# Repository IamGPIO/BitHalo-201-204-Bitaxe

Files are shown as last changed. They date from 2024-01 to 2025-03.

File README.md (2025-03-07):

***

### The BitHalo by IAmGPIO of www.thesolomining.co

In the grand tapestry of the cosmos, where stars weave the stories of fate and fortune, the Almighty leaned over to the legendary IAmGpio, whispering through the winds of time, __'Let there be light.'__ With a smirk as wide as the horizon and the casual air of a cosmic pub regular, IAmGpio, the electric alchemist, declared with a mischievous twinkle, 'Hold my beer...' And thus, amidst a backdrop of chuckling constellations, the darkness scurried away, leaving behind a spectacle to be remembered.

During this celestial extravaganza, as the light began to weave and dance through the fabric of space, the Almighty paused, squinted through the cosmic kaleidoscope, and in a moment of divine epiphany, exclaimed in a cockney accent that resonated across the heavens, _'Oi, hold up, this looks a bit like a halo, don’t it?'_ The cosmos held its breath, the stars blinked in amusement, and in that whimsical pause, BitHalo was born. With a hearty chuckle and a nod of approval, the Lord mused, 'Well, ain’t that brilliant? BitHalo it is, then!' And the universe, in all its wonder and wit, echoed with laughter, forever cherishing the birth of BitHalo, a light that forever wears its halo with a determined grin; proving its sidekick, The Bitaxe, is submitting its best efforts to find that elusive block. 
***
-Ok, this didn't happen _**exactly**_ like this....

***

<p align="center">
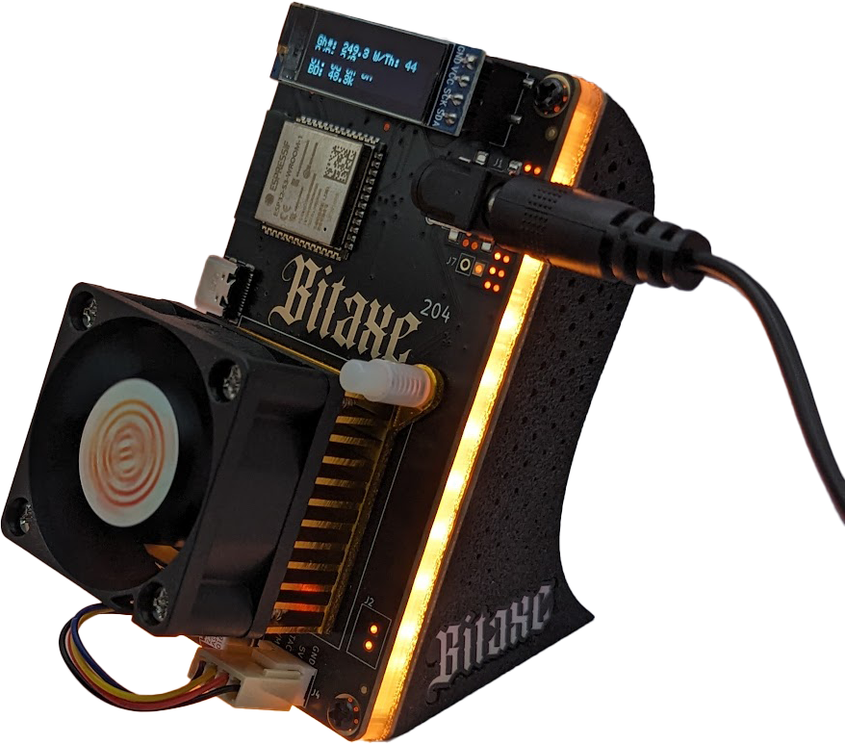
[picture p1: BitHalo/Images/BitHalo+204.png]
Front isometric with logo
  
</p>

***   
License

This project is licensed under the Creative Commons Attribution-ShareAlike 4.0 International License - see the [LICENSE](LICENSE) file for details or visit [Creative Commons Attribution-ShareAlike 4.0 International License](https://creativecommons.org/licenses/by-sa/4.0/).

***
### Anyway...!  

The BitHalo is a daughter board for the Bitaxe (https://bitaxe.org/) and is designed to fix to the rear of the Bitaxe with almost zero technical skill required.
Every time the Bitaxe submits a share to the pool, a pulse of light is emitted from the BitHalo. 

The BitHalo has an in-built ATMEGA328P chip (Arduino) with code uploaded to simply read the debug serial data coming from a test pin (TP18) on the rear of the Bitaxe. When the serial string "accepted" is detected, the function "pulseLeds" is run.

The same applies to "BLOCK FOUND" (that would be nice, wouldn't it!)
<br>
   
***

### The YouTube Intro' VT'!
Somthing I made one eve' with the help of a few glasses of red...

<a href="https://www.youtube.com/watch?v=f2CNs3iYBb0">
    YouTube Video
</a>

***

### The LEDS & Switch on the BitHalo:
On the BitHalo are 30 x RGB side emitting leds (WS protocol). Each LED is individually addressable.
Future revisions of the arduino sketch (BitHalo's firmware) could allow so much more animation options based on the serial stream.

On the BitHalo is a slide switch. This switch simply disables the LED lights on the BitHalo. Turning the LEDs off does not affect the function of the Bitaxe itself. It is just there to turn the lights off if they annoy you at night or whatever.

<p align="center">
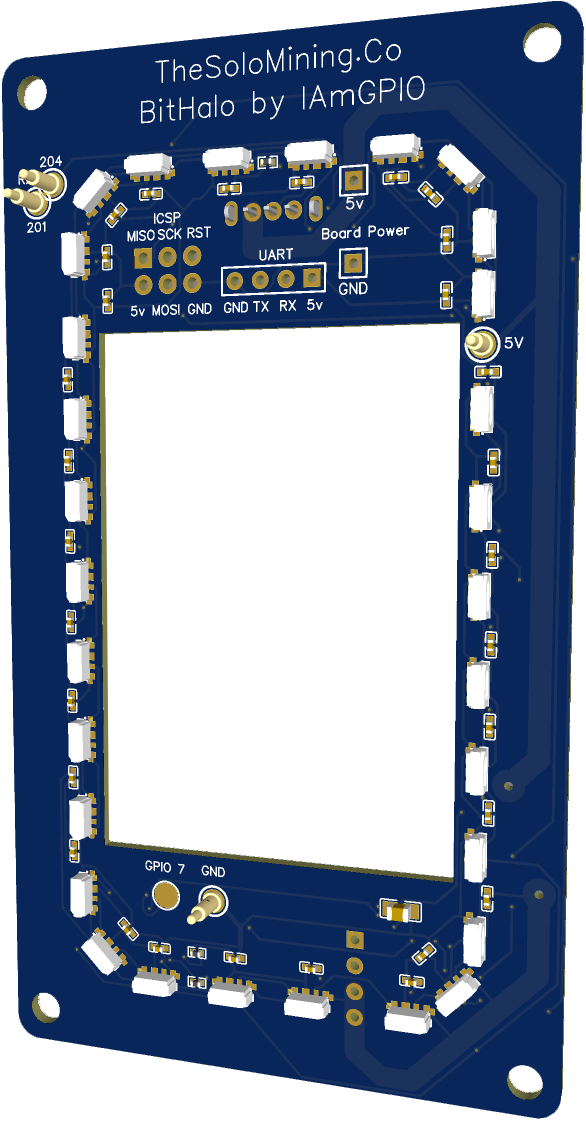
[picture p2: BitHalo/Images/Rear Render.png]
Rear Render

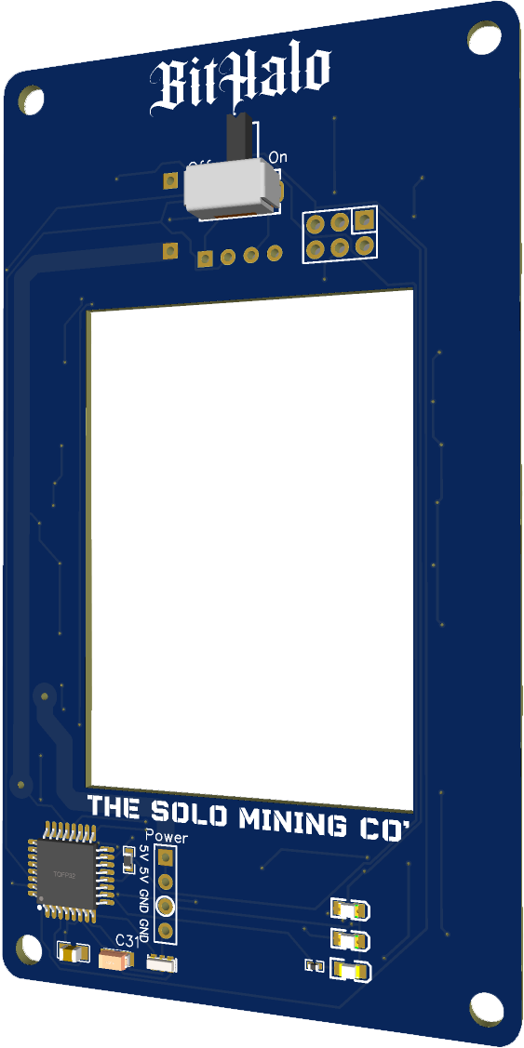
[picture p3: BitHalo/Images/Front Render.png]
Rear Render
 
</p>

***

### The External DC Jack (Do not use if using Bitaxe version 204):
The external DC jack that solders to the rear of the BitHalo was incorporated to allow the Bitaxe to be powered from the rear as opposed to being powered by the DC jack on the side. 

It involved soldering 2 wires on the rear of the BitHalo v201 to the rear of the DC jack on the Bitaxe (wires must be capable of carrying at least 4a of current). Whilst this worked well on Bitaxe v201, I had to omit it for the v204 rollout due to the change in architecture and the way the DC jack was soldered on to the board. V201 had a through hole DC jack and 204 had a surface mount (SMD) variant which meant I couldn't solder on to the pins on the rear.

__Note:__ V205 of the Bitaxe has specific pads for accessories such as the BitHalo. On this, there will be new version of the BitHalo (in due course) which should work with all future versions of the Bitaxe, including the 400 series - "The Supra".

<p align="center">
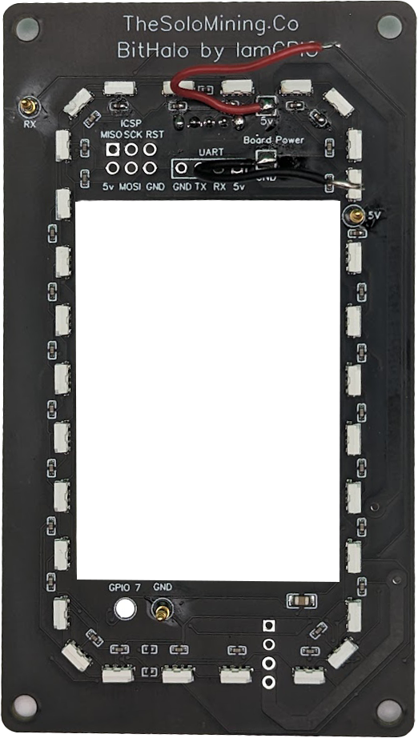
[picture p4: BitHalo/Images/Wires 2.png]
Wires + v201
   
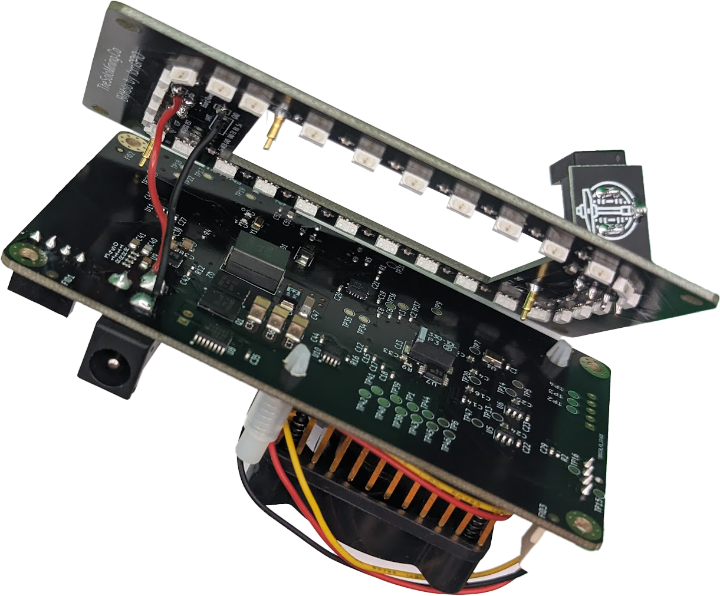
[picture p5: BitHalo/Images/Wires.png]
Wires + v201
   
</p>

***
### The 3d Printed Diffuser:
To diffuse the pixelation from the individual LED's, I have designed a 5mm thick 3d printed opaque/opal diffuser.
This simply prints with 100% infill. File can be found in the "3d Print Files" above. If the 3d printed diffuser fouls any of the components on the Bitaxe or BitHalo, it means the diffuser is the wrong way round!

<p align="center">
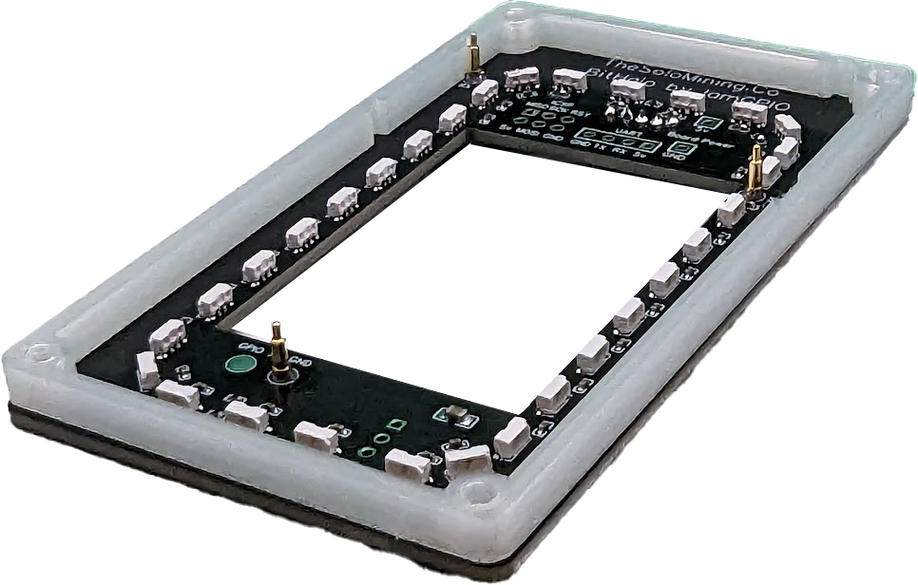
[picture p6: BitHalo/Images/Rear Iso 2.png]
  
</p>

***
### The 3d Printed Stand:
In the 3D print file set above, you will find the left and right sides of the stand I have designed to work with the BitHalo + v201-v204 of the Bitaxes. Careful consideration has been made with regards to the small components on the BitHalo and Bitaxe itself. The stand, nor the diffuser, should foul any components. 

***

### The PCB Files:
So as I am self taught and live under a well-illuminated rock, I have only ever used "Easy-EDA" design software for the circuit and gerber files. The files are available above. You may be able to import directly to KiCad or equiv'. Easy-EDA can be found here: https://easyeda.com/

***

### The Code & updating the BitHalo
As I only know what I know, I have written all of the code in Arduino using the Arduino IDE (sorry about that). The BitHalo can be updated via a "USBasp Programmer" (a few bucks online). On the rear of the BitHalo, you will see the 6 ICSP holes. You connect your USBasp programmer (using 5v) to the 6 pins on the BitHalo. 

As @BenJah rightly pointed out, you will need the FastLED Library installed in the Arduino IDE.

<p align="center">
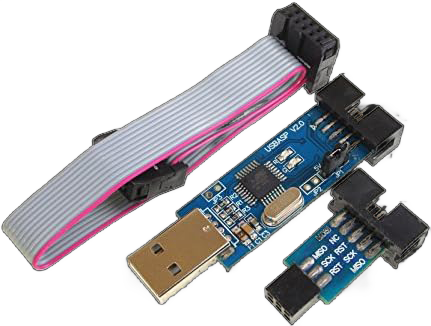
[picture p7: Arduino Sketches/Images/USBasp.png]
  
</p>

When programming via the Arduino IDE, you must click "update using programmer", not the usual "upload" button.
The processor on the BitHalo is the ATMega328p.

If you are flashing the BitHalo in situ (already on the Bitaxe), flick the switch to the off position as this will isolate the BitHalo from the Bitaxe and allow you to power the BitHalo without also trying to power the Bitaxe via the ICSP pins (bad JuJu if this happens).

<p align="center">
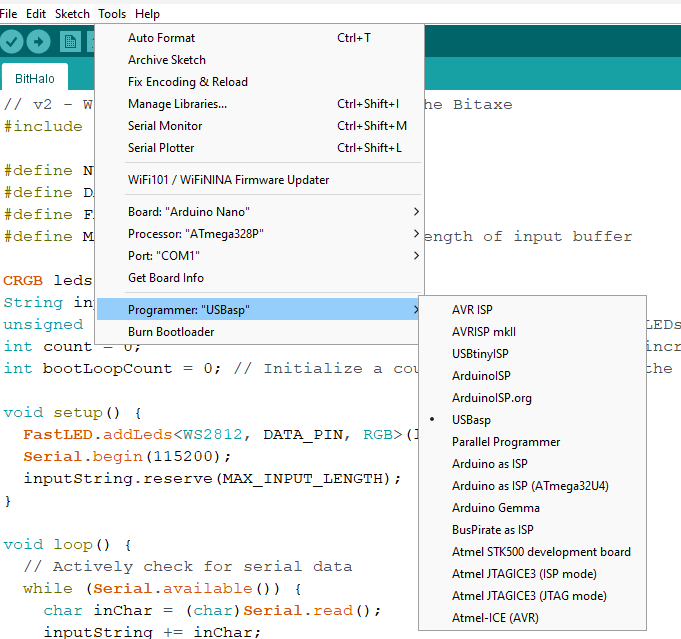
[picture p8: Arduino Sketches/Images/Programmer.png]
   
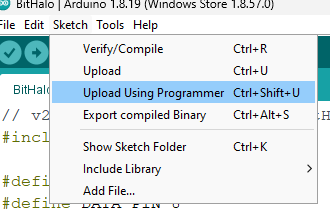
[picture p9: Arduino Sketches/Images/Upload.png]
   
</p>

### The Assembly:
You will need 4 x (M3 x 14mm) self tapping screws. The screws simply pass through the Bitaxe, the diffuser, the BitHalo and then finally into the stands. The 3 x gold pogo pins on the BitHalo will align to the 3 necessary pads on the Bitaxe. Everything self aligns providing you use the correct screws.

<p align="center">
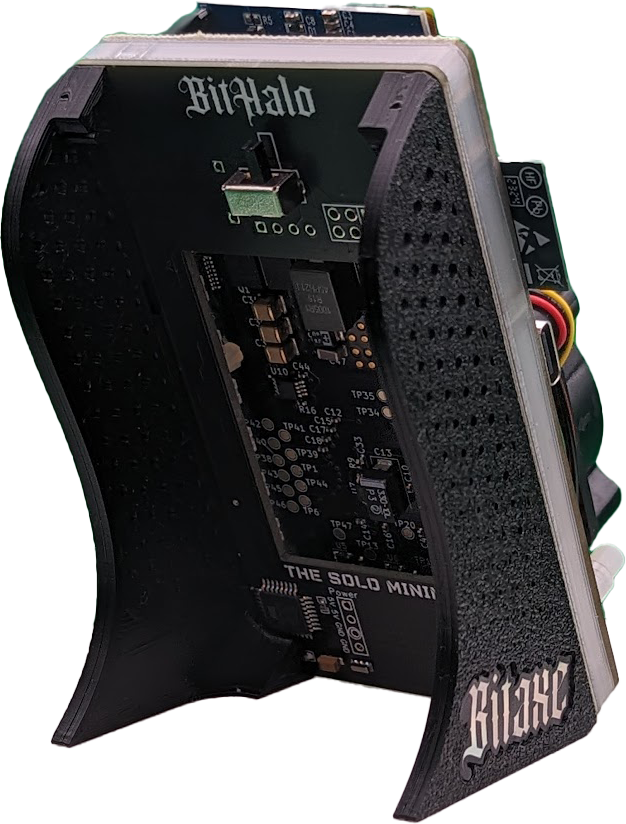
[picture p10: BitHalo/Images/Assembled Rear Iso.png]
  
</p>

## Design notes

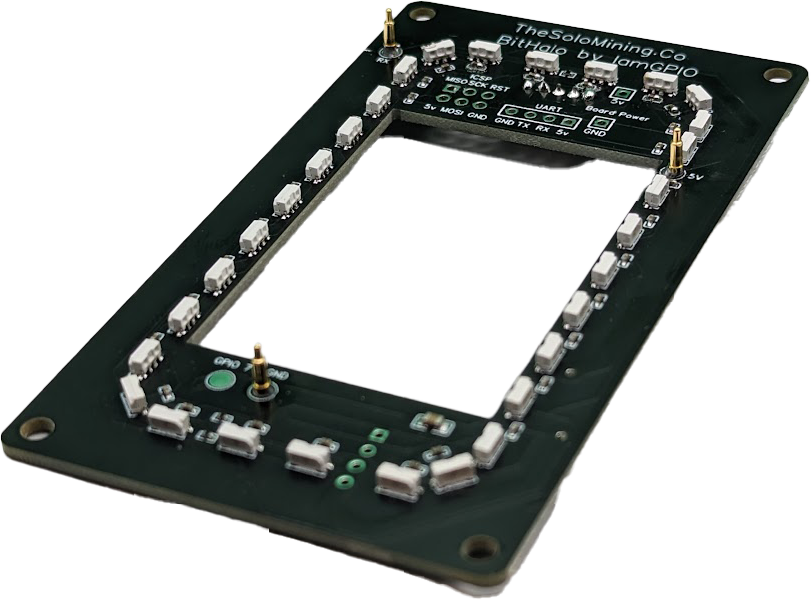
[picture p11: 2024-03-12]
BitHalo/Images/Rear Iso 1.png

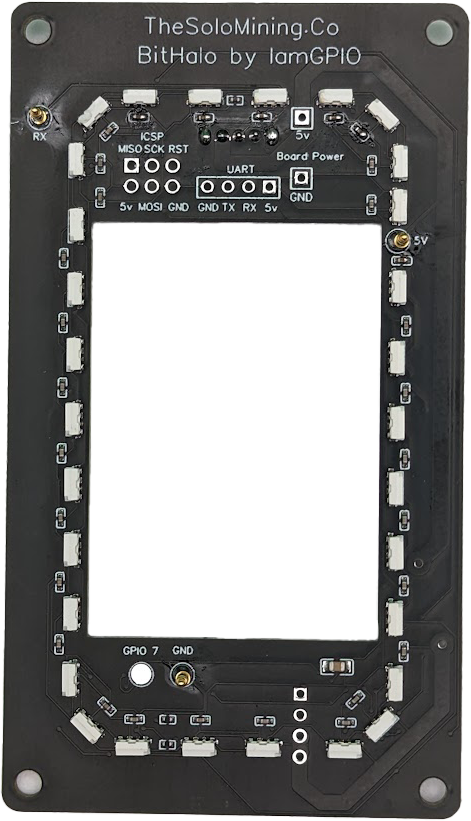
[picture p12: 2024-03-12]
BitHalo/Images/Rear 1.png

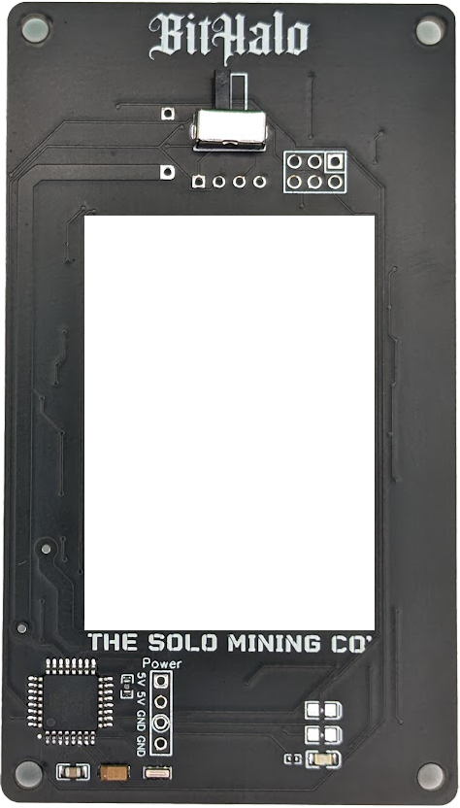
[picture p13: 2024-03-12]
BitHalo/Images/Front 1.png

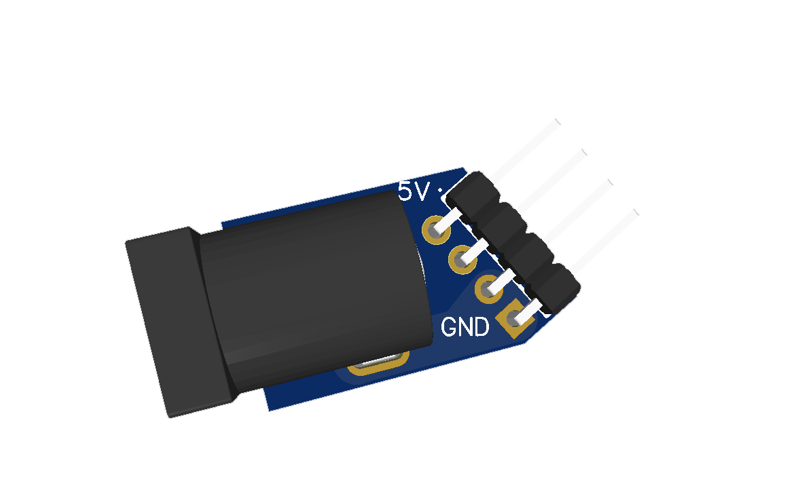
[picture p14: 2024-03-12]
Optional DC Jack/DC Jack Front.png

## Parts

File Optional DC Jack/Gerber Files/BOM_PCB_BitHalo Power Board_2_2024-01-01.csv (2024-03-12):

ID | Name | Designator | Footprint | Quantity | Manufacturer Part | Manufacturer | Supplier | Supplier Part | Price
1 | 2.54-1*4P反弯排针 | H1 | HDR-TH_4P-P2.54-H-M-W10.4 | 1 | 2.54-1*4P反弯排针 | BOOMELE(博穆精密) | LCSC | C91552 | 0.023
2 | DC-005-5A-2.0 | . | DC-IN-TH_DC-005-5A-2.0 | 1 | DC-005-5A-2.0 | XKB Enterprise | LCSC | C381116 | 0.213

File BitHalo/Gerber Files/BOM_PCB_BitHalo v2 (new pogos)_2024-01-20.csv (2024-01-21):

ID | Name | Designator | Footprint | Quantity | Manufacturer Part | Manufacturer | Supplier | Supplier Part | Price
1 | YTC1P-4020-01 | 5V,GND,RX204,RX201 | TESTPOINT-SMD_BD2.0_YTC1P-4020-01 | 4 | YTC1P-4020-01 | YIYUAN(怡远) | LCSC | C5221284 | 0.099
2 | SK6812SIDE-A-RVS | LED1,LED3,LED4,LED6,LED22,LED2,LED5,LED7,LED8,LED9,LED10,LED11,LED12,LED13,LED14,LED15,LED16,LED17,LED18,LED19,LED20,LED21,LED23,LED24,LED25,LED26,LED27,LED28,LED29,LED30 | LED-SMD_4P-L4.0-W1.6-L | 30 | SK6812SIDE-A-RVS | 欧思科光电 | LCSC | C2890037 | 0.175
3 | 100nF | C8,C9,C10,C11,C12,C13,C14,C15,C16,C17,C18,C19,C20,C21,C22,C23,C24,C25,C26,C27,C28,C29,C1,C2,C3,C4,C5,C6,C7,C33 | C0402 | 30 | CT41G-0402-2X1-16V-0.1μF-K(N) | TORCH(火炬) | LCSC | C141382 | 0.003
4 | 100nF | C30,C32 | C0805 | 2 | C0805C104K5RACTU | KEMET(基美) | LCSC | C3018562 | 0.019
5 | 330Ω | R6,R7,R10 | R0402 | 3 | 0402WGF6800TCE | UNI-ROYAL(厚声) | LCSC | C364993 | 0.006
6 | 1kΩ | R8 | R0402 | 1 | RC0402FR-071KL | YAGEO(国巨) | LCSC | C106235 | 0.001
7 | 4.7uF | C31 | CASE-A_3216 | 1 | CA45-A016K475T | 湘怡中元/湘江 | LCSC | C123256 | 0.065
8 | APT2012CGCK | DATA,POWER | LED-SMD_L2.0-W1.3-R-RD | 2 | APT2012CGCK | Kingbright | LCSC | C5875740 | 0.115
9 | 300Ω | R5 | R0603 | 1 | 0603WAF3000T5E | UNI-ROYAL(厚声) | LCSC | C23025 | 0.001
10 | ATMEGA328P-AU | U1 | TQFP-32_L7.0-W7.0-P0.80-LS9.0-BL | 1 | ATMEGA328P-AU | MICROCHIP(美国微芯) | LCSC | C14877 | 2.202
11 | LTST-C170TBKT | SRX | LED0805-RD_BLUE | 1 | LTST-C170TBKT | LITEON(光宝) | LCSC | C98222 | 0.023
12 | 16MHz | X1 | OSC-SMD_3P-L3.2-W1.3-P0.95-L | 1 | CSTCE16M0V53-R0 | muRata(村田) | LCSC | C32180 | 0.236
13 | SK12D07VG5_C3020419 | SWITCH | SW-TH_SHOU_SK12D07VG5 | 1 | SK12D07VG5 | SHOU HAN(首韩) | LCSC | C3020419 | 0.017

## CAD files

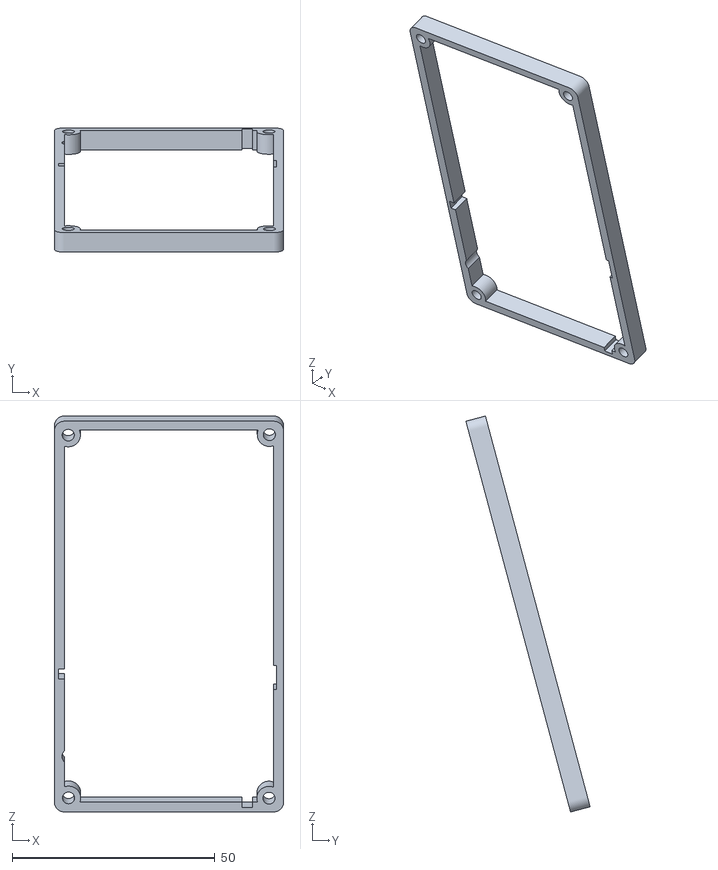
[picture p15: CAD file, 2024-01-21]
3d Print Files/3d Printed Halo 5mm Opaque.stl
56.5 x 30.6 x 97.6

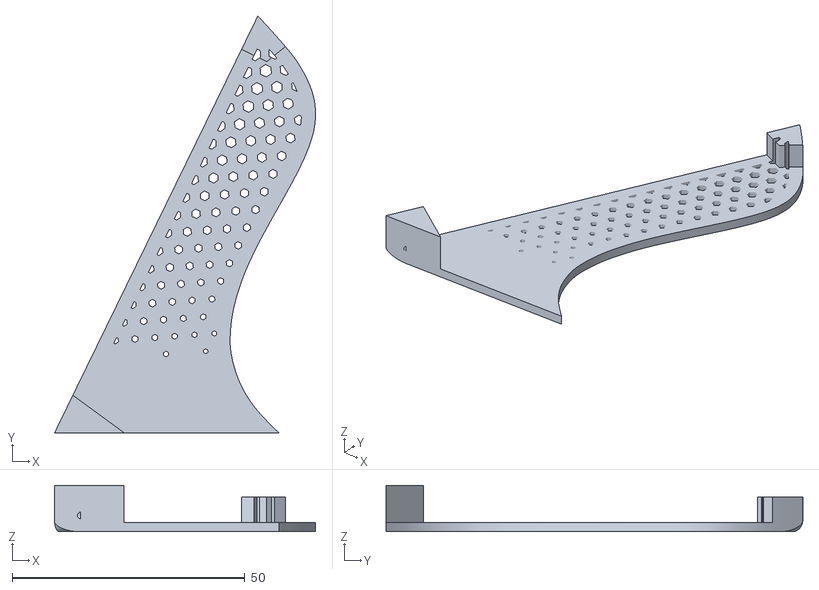
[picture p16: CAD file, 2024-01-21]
3d Print Files/Stand - Left.stl
56.1 x 89.6 x 10.0

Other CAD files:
3d Print Files/Stand - Right.stl

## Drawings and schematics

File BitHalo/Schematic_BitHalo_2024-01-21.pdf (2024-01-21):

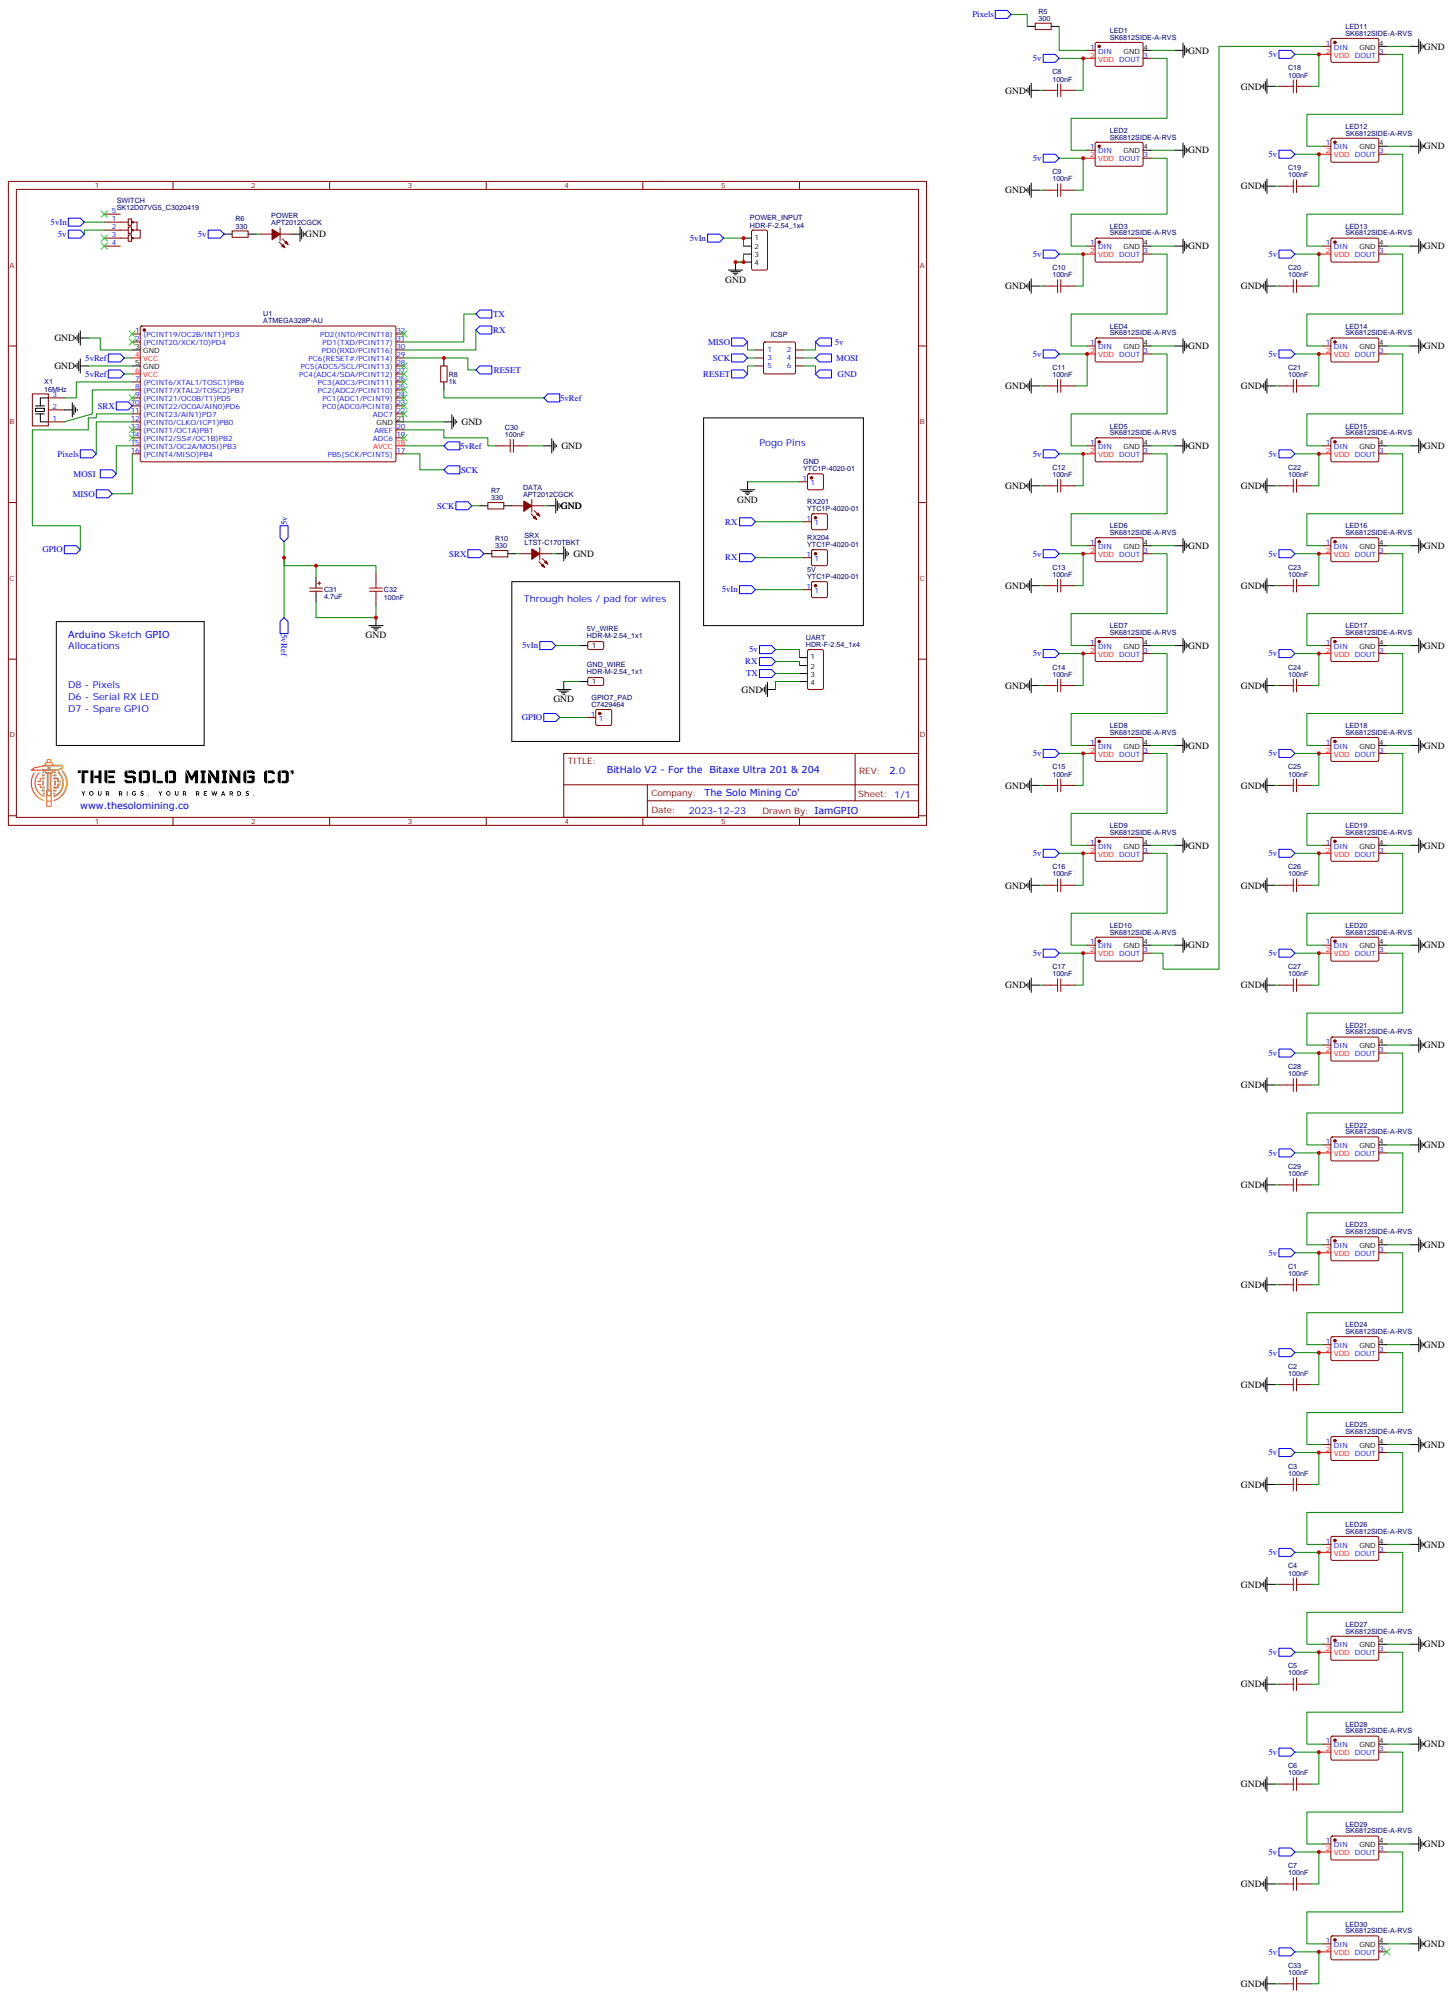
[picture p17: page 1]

Through holes / pad for wires

BitHalo V2 - For the Bitaxe Ultra 201 & 204

Company: The Solo Mining Co'

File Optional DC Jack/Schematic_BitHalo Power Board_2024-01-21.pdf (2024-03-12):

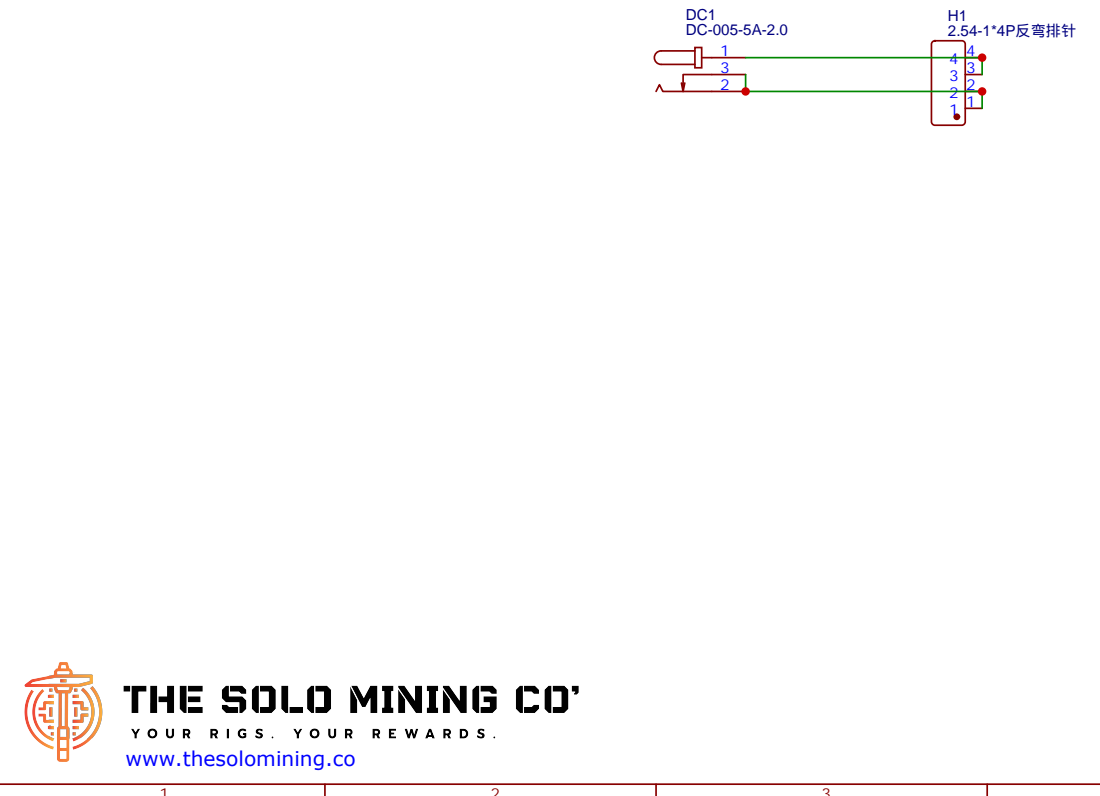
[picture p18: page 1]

Company: The Solo Mining Co'

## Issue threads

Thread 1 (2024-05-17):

Feature Request: flush_work notification

recklessnode, 2024-05-17:
This is a placeholder until I get a bithalo and can play with it, or if someone else wants to implement.

Feature Request:
When the ASIC receives the "flush_work" instruction from the stratum server, notify the operator through the BitHalo by draining all LEDs to off (something distinct from the share submitted or block found actions) and then filling again with the default halo color, or an intermediary color or pattern (two flashes perhaps?) and then back to the normal loop.

This would work well in conjunction with a BlockClock so the operator can visualize how the ASIC is aware that a block has been found before the electrum server can tell the BlockClock to refresh, alternatively, if coupled with a BitAxe NerdMiner display, the blockheight can increment on the display as the halo flashes which would make it doubly impressive!

recklessnode, 2024-05-17:
another thought would be to flash on rejected "Stale share" (rapid doubleflash red/blue maybe?) so you can see when flush work occurs and the next pending share gets rejected by the stratum server, or if your rig is having issues submitting shares it's a good indicator as well. Also, if cgminer is idle (no network let's say) the base halo color should be different from if it's online and hashing. Sorry to spam with ideas! I was also thinking it could ramp up the color based on the ASIC temperature if we can read that in, so it starts off yellow and fades to orange as it starts hashing and heats up. Then it flashes with work submitted, all work flushed, and shares rejected as indicators of what's going on "behind the curtain", especially valuable from an educational standpoint in the classroom!

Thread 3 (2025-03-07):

Update Arduino sketch with Rear button support

GuillaumeLazar, 2025-03-07:
Thank you for providing the Arduino source code of the BitHalo !

Can you provide the updated version of the Arduino source code with the Rear button support, please ?
I would like to add features to this project, but I don't want to lose the rear button to change color.

GuillaumeLazar, 2025-03-07:
Thanks!

Closed 2025-03-07.

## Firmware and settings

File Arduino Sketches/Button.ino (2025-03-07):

// v2 - Written by IamGPIO - BitHalo for the Bitaxe
#include <FastLED.h>

#define NUM_LEDS 30
#define DATA_PIN 8
#define BUTTON_PIN 6          // Button pin
#define FADE_SPEED 5
#define MAX_INPUT_LENGTH 200  // Maximum length of input buffer
#define MAX_NUMBER 8          // Maximum number for LED colors

CRGB leds[NUM_LEDS];
String inputString = "";        
unsigned long previousMillis = 0;           // Stores last time LEDs were updated
int count = 0;                              // Stores count for incrementing up to the NUM_LEDs
int bootLoopCount = 0;                      // Initialize a counter to keep track of the number of BootLoops
int currentNumber = 0;                      // Number to determine LED color
bool buttonPressed = false;                 // Flag to track button state

void setup() {
  FastLED.addLeds<WS2812, DATA_PIN, RGB>(leds, NUM_LEDS);
  pinMode(BUTTON_PIN, INPUT_PULLUP);        // Set button pin as input with pull-up resistor
  Serial.begin(115200);
  inputString.reserve(MAX_INPUT_LENGTH); 
}

void loop() {
  // Check for button press
  if (digitalRead(BUTTON_PIN) == LOW) {
    if (!buttonPressed) { // Only act on the first button press
      buttonPressed = true;
      handleButtonPress();
    }
  } else {
    buttonPressed = false; // Reset flag when button is released
  }

  // Actively check for serial data
  while (Serial.available()) {
    char inChar = (char)Serial.read();
    inputString += inChar;

    // Check for newline character or buffer overflow
    if (inChar == '\n' || inputString.length() >= MAX_INPUT_LENGTH) {
      processInput();
    }
  }
}

void processInput() {
  if (inputString.indexOf("accepted") >= 0) {
    pulseLeds();
  }
  
  if (inputString.indexOf("BLOCK FOUND") >= 0) {
    BuyLambo();
  }

  if (inputString.indexOf("Initializing serial") >= 0) {
    for (int i = 0; i < 25000; i++) { // Run BootLoops 25000 times
      BootLoops(0, 100, 255, 30, 30, 1000, 1);
      bootLoopCount++;
      if (bootLoopCount >= 250) {
        break; // Exit the loop after 250 iterations
      }
    }
  }

  // Clear the input string for new data
  inputString = "";
}

void pulseLeds() {
  // Get the color based on the current number
  CRGB color = getColorForNumber(currentNumber);

  // Set all LEDs to the color and then show them
  fill_solid(leds, NUM_LEDS, color);
  FastLED.show();
  delay(200); // Wait for a short period

  // Gradually fade out all LEDs while maintaining the color
  for (int brightness = 255; brightness >= 0; brightness -= FADE_SPEED) {
    CRGB fadedColor = color;
    fadedColor.nscale8(brightness);
    fill_solid(leds, NUM_LEDS, fadedColor);

    FastLED.show();
    delay(20); // Delay to control the speed of the fade out
  }
}

void handleButtonPress() {
  // Increment the current number and wrap around if it exceeds MAX_NUMBER
  currentNumber++;
  if (currentNumber > MAX_NUMBER) {
    currentNumber = 0;
  }

  // Print the current number to Serial for debugging
  Serial.print("Current Number: ");
  Serial.println(currentNumber);

  // Pulse the LEDs to show the new color
  pulseLeds();
}

void BuyLambo() {
  CRGB WHITE = CRGB(255, 255, 255);
  int flashCount = 0;

  while (flashCount < 1000000000) {
    // Turn on all LEDs to white
    fill_solid(leds, NUM_LEDS, WHITE);
    FastLED.show();
    delay(100); // Wait for a short period

    // Turn off all LEDs
    fill_solid(leds, NUM_LEDS, CRGB::Black);
    FastLED.show();
    delay(100); // Wait for a short period

    flashCount++;
  }
}

void BootLoops(int red, int green, int blue, int tail_length, int delay_duration, int interval, int direction) {
  unsigned long currentMillis = millis();   // Get the time
  if (currentMillis - previousMillis >= interval) {
    previousMillis = currentMillis;         // Save the last time the LEDs were updated
    count = 0;                              // Reset the count to 0 after each interval
  }
  if (direction == -1) {        // Reverse direction option for LEDs
    if (count < NUM_LEDS) {
      leds[NUM_LEDS - (count % (NUM_LEDS + 1))].setRGB(red, green, blue);    // Set LEDs with the color value
      count++;
    }
  } else {
    if (count < NUM_LEDS) {     // Forward direction option for LEDs
      leds[count % (NUM_LEDS + 1)].setRGB(red, green, blue);    // Set LEDs with the color value
      count++;
    }
  }
  fadeToBlackBy(leds, NUM_LEDS, tail_length);                 // Fade the tail LEDs to black
  FastLED.show();
  delay(delay_duration);                                      // Delay to set the speed of the animation
}

// Function to map numbers to colors
CRGB getColorForNumber(int number) {
  switch (number) {
    case 0: return CRGB(50, 255, 0);   // Orange (GRB: G=165, R=255, B=0)
    case 1: return CRGB(0, 255, 0);   // Red (GRB: G=255, R=0, B=0)
    case 2: return CRGB(255, 0, 0);   // Green (GRB: G=0, R=255, B=0)
    case 3: return CRGB(0, 0, 255);   // Blue (GRB: G=0, R=0, B=255)
    case 4: return CRGB(255, 0, 255); // Cyan (GRB: G=255, R=0, B=255)
    case 5: return CRGB(0, 255, 255); // Magenta (GRB: G=0, R=255, B=255)
    case 6: return CRGB(255, 255, 0); // Yellow (GRB: G=255, R=255, B=0)
    case 7: return CRGB(0, 128, 128); // Purple (GRB: G=128, R=0, B=128)
    case 8: return CRGB(150, 150, 150); // White (GRB: G=255, R=255, B=255)
    default: return CRGB(0, 0, 0);     // Black (off)
  }
}

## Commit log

2024-03-12 Rename Arduino Sketches/Programmer.png to Arduino Sketches/Images/Programmer.png
2024-03-12 Rename Arduino Sketches/Upload.png to Arduino Sketches/Images/Upload.png
2025-03-07 Add files via upload
    New sketch to accomodate the new rear button for selecting the color of the share submission flash.
